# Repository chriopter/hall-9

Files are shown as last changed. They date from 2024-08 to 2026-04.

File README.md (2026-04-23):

# hall-9

Local voice assistant for Home Assistant, running on ESPHome with Hall-9 hardware.

Local/offline STT/TTS with wake word on ESP32-S3.

## Hardware

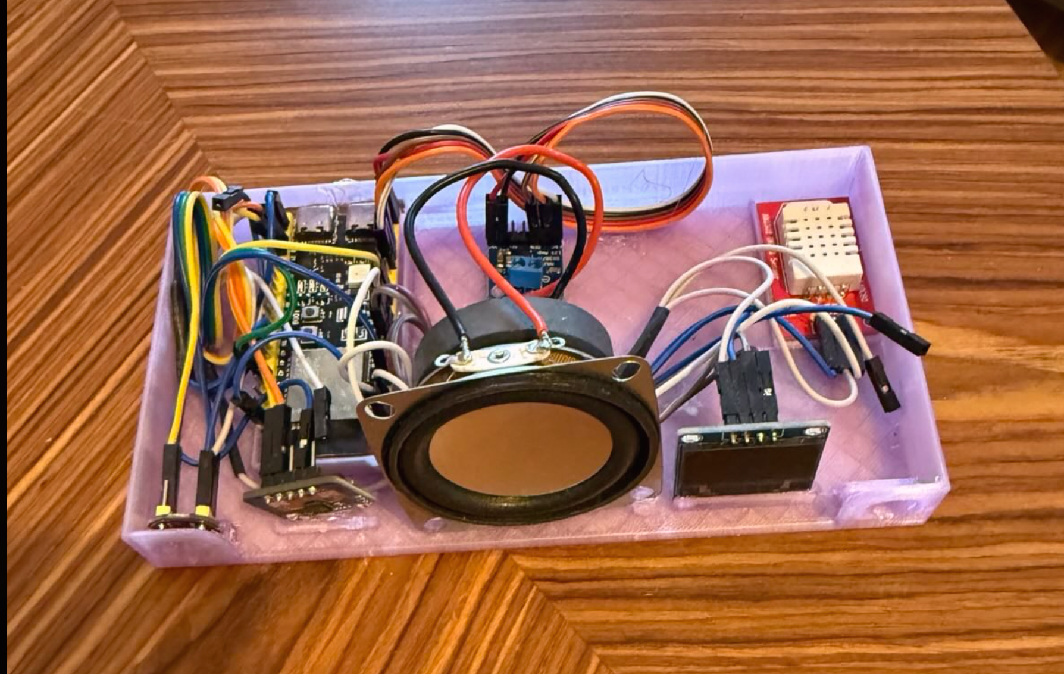
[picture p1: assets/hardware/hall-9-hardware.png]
Hall-9 hardware


### Hardware Parts

- ESP32-S3
- MAX98357 amplifier + speaker (4 Ω / 8 Ω)
- INMP441 microphone
- SSD1306 display
- DHT22 thermometer (optional)

### Bench Case

Use the bench case in `assets/case/` during development.

### Wiring

Follow the pinout from `hall-9.yaml`. Provide 5 V for the MAX98357; some ESP32-S3 boards can supply this directly.

## Install

Minimal ESPHome package stub for Home Assistant or the ESPHome Device Builder:

```yaml
substitutions:
  device_name: hall-9
  device_friendly_name: Hall 9

packages:
  hall9:
    url: https://github.com/chriopter/hall-9
    ref: dev
    files: [hall-9.yaml]

api:
  encryption:
    key: "YOUR_API_KEY"

ota:
  - platform: esphome
    password: "YOUR_OTA_PASSWORD"

wifi:
  ssid: !secret wifi_ssid
  password: !secret wifi_password
  ap:
    ssid: "Hall-9 Fallback Hotspot"
    password: "YOUR_FALLBACK_PASSWORD"

captive_portal:
```

<details>
<summary>Development</summary>

Local compile via the official ESPHome Docker image — no Python/ESPHome install needed.

1. Create `secrets.yaml` in the repo root (gitignored):

   ```yaml
   wifi_ssid: "YourSSID"
   wifi_password: "YourPassword"
   ```

2. Create a local wrapper, e.g. `hall-9.local.yaml` (gitignored):

   ```yaml
   substitutions:
     device_name: hall-9
     device_friendly_name: Hall 9

   esphome:
     name: ${device_name}
     friendly_name: ${device_friendly_name}

   packages:
     hall9: !include hall-9.yaml

   api:
     encryption:
       key: "REPLACE_WITH_BASE64_KEY"

   ota:
     - platform: esphome
       password: "REPLACE_WITH_OTA_PASSWORD"

   wifi:
     ssid: !secret wifi_ssid
     password: !secret wifi_password
     ap:
       ssid: "Hall-9 Fallback Hotspot"
       password: "REPLACE_WITH_AP_PASSWORD"

   captive_portal:
   ```

3. Compile:

   ```bash
   docker run --rm -v "$PWD":/config esphome/esphome compile hall-9.local.yaml
   ```

4. Flash — OTA over WiFi:

   ```bash
   docker run --rm --network=host -v "$PWD":/config esphome/esphome run hall-9.local.yaml --device <device-ip>
   ```

   Or via USB serial:

   ```bash
   docker run --rm --device=/dev/ttyACM0 -v "$PWD":/config esphome/esphome run hall-9.local.yaml
   ```

First run pulls the ESP-IDF toolchain (~2–3 GB). Build artifacts land in `.esphome/` (gitignored).

Optional hardware (DHT22, SSD1306 display) is wired via `packages:` in `hall-9.yaml` — comment out a line there to disable.

</details>

## Credits

- Inspired by [esphome/home-assistant-voice-pe](https://github.com/esphome/home-assistant-voice-pe) — Home Assistant Voice Preview Edition.
- `sounds/timer_finished.flac` © 2024 [Clayton Charles Tapp](https://www.cctaudio.com/), licensed under [CC BY 4.0](https://creativecommons.org/licenses/by/4.0/), originally from Home Assistant Voice Preview Edition. See `sounds/LICENSE.md`.

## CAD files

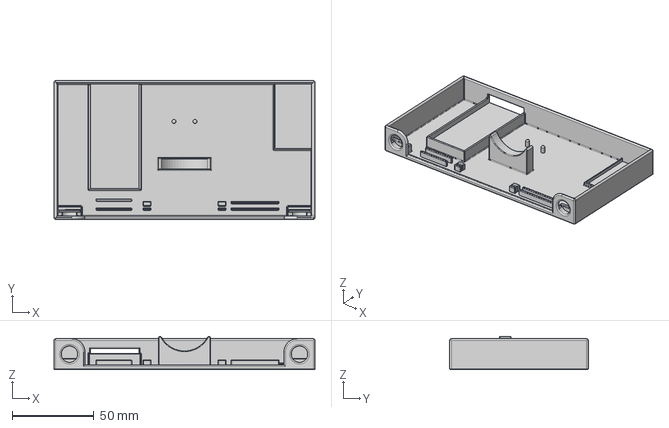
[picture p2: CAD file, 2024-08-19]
assets/case/Bench.step
160.0 x 85.0 x 20.5 mm

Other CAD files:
assets/case/Bench.f3d

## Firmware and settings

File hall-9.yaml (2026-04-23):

packages:
  dht22: !include modules/dht22.yaml
  display: !include modules/display.yaml

esp32:
  board: esp32-s3-devkitc-1
  variant: esp32s3
  flash_size: 16MB
  framework:
    type: esp-idf
    version: recommended
    sdkconfig_options:
      CONFIG_ESP32S3_DEFAULT_CPU_FREQ_240: "y"
      CONFIG_ESP32S3_DATA_CACHE_64KB: "y"
      CONFIG_ESP32S3_DATA_CACHE_LINE_64B: "y"
      CONFIG_ESP32S3_INSTRUCTION_CACHE_32KB: "y"
      CONFIG_BT_ALLOCATION_FROM_SPIRAM_FIRST: "y"
      CONFIG_BT_BLE_DYNAMIC_ENV_MEMORY: "y"
      CONFIG_MBEDTLS_EXTERNAL_MEM_ALLOC: "y"
      CONFIG_MBEDTLS_SSL_PROTO_TLS1_3: "y"
      # N16R8: code + rodata live in 80 MHz octal PSRAM so internal SRAM stays
      # free for audio/WiFi tasks — Voice PE-style.
      CONFIG_SPIRAM_RODATA: "y"
      CONFIG_SPIRAM_FETCH_INSTRUCTIONS: "y"

psram:
  mode: octal
  speed: 80MHz

# Apply the persisted speaker_volume slider value once components are up.
# `set_action` on the number does not fire on boot when restoring state.
# Also force-disable the stop wake-word model on boot — ESPHome persists the
# enabled state to flash, so "stop" could stay armed after a timer ring.
esphome:
  on_boot:
    priority: -100
    then:
      - speaker.volume_set:
          id: hw_speaker
          volume: !lambda |-
            float x = id(speaker_volume).state;
            return x <= 0.0f ? 0.0f : pow(x, 0.15f);
      - micro_wake_word.disable_model: stop_model

logger:

api:
  on_client_connected:
    then:
      - delay: 50ms
      - light.turn_off: led_ww
      - micro_wake_word.start:
  on_client_disconnected:
    then:
      - voice_assistant.stop:

# --- I/O pins ---
i2c:
  sda: GPIO16
  scl: GPIO15
  scan: true
  frequency: 400kHz

i2s_audio:
  - id: i2s_in
    i2s_lrclk_pin: GPIO8
    i2s_bclk_pin: GPIO2
  - id: i2s_speaker
    i2s_lrclk_pin: GPIO10
    i2s_bclk_pin: GPIO11

switch:
  - platform: gpio
    pin: GPIO45
    id: led_ring_power
    restore_mode: ALWAYS_ON
    internal: true

  - platform: gpio
    pin: GPIO47
    id: speaker_amp_power
    restore_mode: ALWAYS_ON
    internal: true

  - platform: template
    id: timer_ringing
    optimistic: true
    internal: true
    restore_mode: ALWAYS_OFF
    on_turn_on:
      - light.turn_on:
          id: led_ww
          effect: "timer_ring"
      - micro_wake_word.enable_model: stop_model
      - script.execute: timer_ring_timeout
      - script.execute: ring_timer_loop
    on_turn_off:
      - script.stop: timer_ring_timeout
      - script.stop: ring_timer_loop
      - media_player.stop:
          id: announcement_media_player
      - micro_wake_word.disable_model: stop_model
      - light.turn_off: led_ww
      # Force display back to clock. Do NOT call update() from a lambda here —
      # that races with the I2C bus during audio playback and crashes SSD1306.
      # Only flip the page pointer; the 500 ms auto-interval re-renders it.
      - lambda: |-
          id(is_timer_active) = false;
          id(voice_assistant_phase) = 1;
      # Re-arm wake-word detection — the media_player announcement pipeline
      # can leave MWW inference paused after the ring ends.
      - micro_wake_word.start:

  - platform: template
    id: mute
    name: Mute
    optimistic: true
    on_turn_on:
      - micro_wake_word.stop:
      - voice_assistant.stop:
      - light.turn_on:
          id: led_ww
          red: 100%
          green: 0%
          blue: 0%
          brightness: 30%
    on_turn_off:
      - micro_wake_word.start:
      - light.turn_off: led_ww

script:
  - id: timer_ring_timeout
    mode: restart
    then:
      - delay: 2min
      - switch.turn_off: timer_ringing

  - id: ring_timer_loop
    mode: restart
    then:
      - while:
          condition:
            switch.is_on: timer_ringing
          then:
            - media_player.speaker.play_on_device_media_file:
                id: announcement_media_player
                media_file: timer_finished_sound
                announcement: true
            - delay: 4s

number:
  - platform: template
    id: speaker_volume
    name: "Speaker Volume"
    icon: mdi:volume-high
    mode: slider
    optimistic: true
    restore_value: true
    min_value: 0.0
    max_value: 1.0
    step: 0.05
    initial_value: 0.7
    set_action:
      # Perceptual loudness curve (pow 0.15): linear sliders feel flat because
      # hearing is logarithmic. 0.5 maps to ~0.9 real volume.
      - speaker.volume_set:
          id: hw_speaker
          volume: !lambda "return x <= 0.0f ? 0.0f : pow(x, 0.15f);"

button:
  - platform: restart
    name: "Restart"

  - platform: safe_mode
    name: "Restart (Safe Mode)"

  - platform: factory_reset
    name: "Factory Reset"

  - platform: template
    name: "Trigger Voice Assistant"
    icon: mdi:microphone
    on_press:
      - voice_assistant.start:
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

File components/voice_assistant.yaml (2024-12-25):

# Contails Microphone, Speaker, Voice Assistant, Status Light and Display Configuration

voice_assistant:
  id: va
  microphone: va_mic
  speaker: va_speaker
  volume_multiplier: 4.0
  on_stt_end:
    then:
      - light.turn_off: led_ww
  on_error:
    - micro_wake_word.start:
  on_end:
    then:
      - light.turn_off: led_ww
      - wait_until:
          not:
            voice_assistant.is_running:
      - micro_wake_word.start:

micro_wake_word:
  models:
    - model: okay_nabu
  on_wake_word_detected:
    - voice_assistant.start:
        wake_word: !lambda return wake_word;
    - light.turn_on:
        id: led_ww
        red: 30%
        green: 30%
        blue: 70%
        brightness: 60%
        effect: fast pulse

switch:
  - platform: template
    id: mute
    name: mute
    optimistic: true
    on_turn_on: 
      - micro_wake_word.stop:
      - voice_assistant.stop:
      - light.turn_on:
          id: led_ww           
          red: 100%
          green: 0%
          blue: 0%
          brightness: 60%
          effect: fast pulse 
      - delay: 2s
      - light.turn_off:
          id: led_ww
      - light.turn_on:
          id: led_ww           
          red: 100%
          green: 0%
          blue: 0%
          brightness: 30%
    on_turn_off:
      - micro_wake_word.start:
      - light.turn_on:
          id: led_ww           
          red: 0%
          green: 100%
          blue: 0%
          brightness: 60%
          effect: fast pulse 
      - delay: 2s
      - light.turn_off:
          id: led_ww 

i2c:
  sda: GPIO16
  scl: GPIO15
  scan: true
  frequency: 400kHz

display:
  - platform: ssd1306_i2c
    model: "SSD1306 128x64"
    rotation: 0
    address: 0x3C
    update_interval: 5s
    lambda: |-
      it.strftime(0, 60, id(font1), TextAlign::BASELINE_LEFT, "%H:%M", id(esptime).now());

light:
  - platform: esp32_rmt_led_strip
    id: led_ww
    rgb_order: GRB
    pin: GPIO48
    num_leds: 1
    rmt_channel: 0
    chipset: ws2812
    name: "on board light"
    effects:
      - pulse:
      - pulse:
          name: "Fast Pulse"
          transition_length: 0.5s
          update_interval: 0.5s
          min_brightness: 0%
          max_brightness: 100%
          
          
 # Audio and Voice Assistant Config          
i2s_audio:
  - id: i2s_in
    i2s_lrclk_pin: GPIO8  #WS 
    i2s_bclk_pin: GPIO2 #SCK
  - id: i2s_speaker
    i2s_lrclk_pin: GPIO10  #LRC 
    i2s_bclk_pin: GPIO11 #BLCK


microphone:
  - platform: i2s_audio
    id: va_mic
    adc_type: external
    i2s_din_pin: GPIO4 #SD pin on the INMP441
    channel: left
    pdm: false
    i2s_audio_id: i2s_in
    bits_per_sample: 32 bit
    
speaker:
    platform: i2s_audio
    id: va_speaker
    i2s_audio_id: i2s_speaker
    dac_type: external
    i2s_dout_pin: GPIO12   #  DIN Pin of the MAX98357A Audio Amplifier
    channel: mono
    bits_per_sample: 32bit
    timeout: 500ms

font:
  - file: "https://raw.githubusercontent.com/chriopter/hall-9/main/assets/fonts/arial.ttf"
    id: font1
    size: 32


# Time configuration (using Home Assistant or NTP server)
time:
  - platform: homeassistant
    id: esptime

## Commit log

2024-08-16 Added Bench Case
    [Bench v50.f3d, Bench v50.step]
2024-08-19 Rename Bench v61.f3d to Bench.f3d
    [Bench.f3d]
2024-08-19 Rename Bench v61.step to Bench.step
    [Bench.step]
2024-12-25 Update and rename assistant.yaml to hall-9.yaml
2026-04-23 add timer
2026-04-23 add timer sound
2026-04-23 adjust timer settings
